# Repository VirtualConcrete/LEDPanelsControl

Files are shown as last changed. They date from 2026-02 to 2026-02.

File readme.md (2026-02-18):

# DMX HUB12 LED driver

Use any HUB12 display with DMX control.

### Schematics

The board is a simple Arduino Nano --> HUB12 adapter with DMX input using the SN75176 differential bus transciver.
XLR 3 pin is used for DMX input.
The power supply is +5V via screw terminals.

### Dependencies

- [DMD2](https://github.com/freetronics/DMD2)
- [DMXSerial](https://github.com/mathertel/DmxSerial)

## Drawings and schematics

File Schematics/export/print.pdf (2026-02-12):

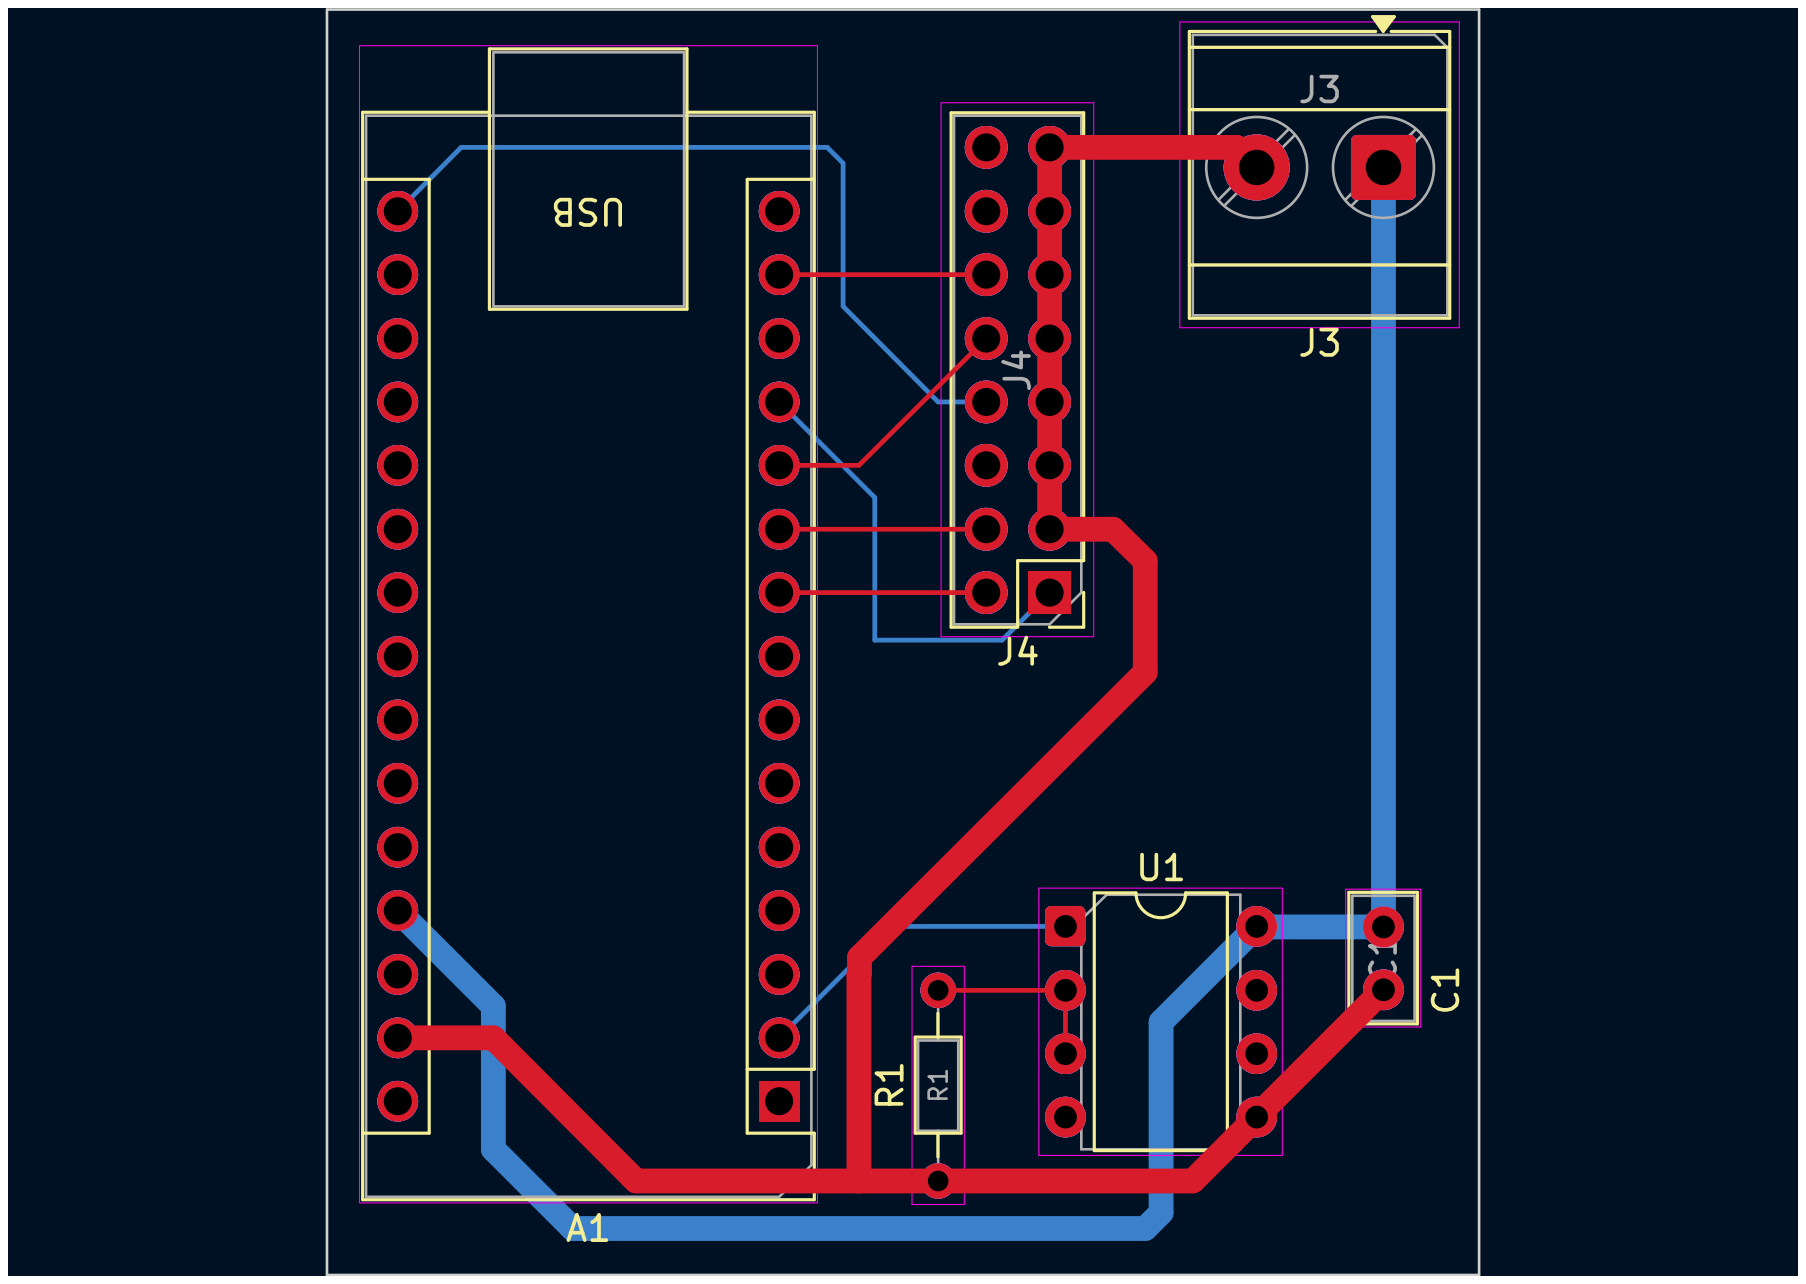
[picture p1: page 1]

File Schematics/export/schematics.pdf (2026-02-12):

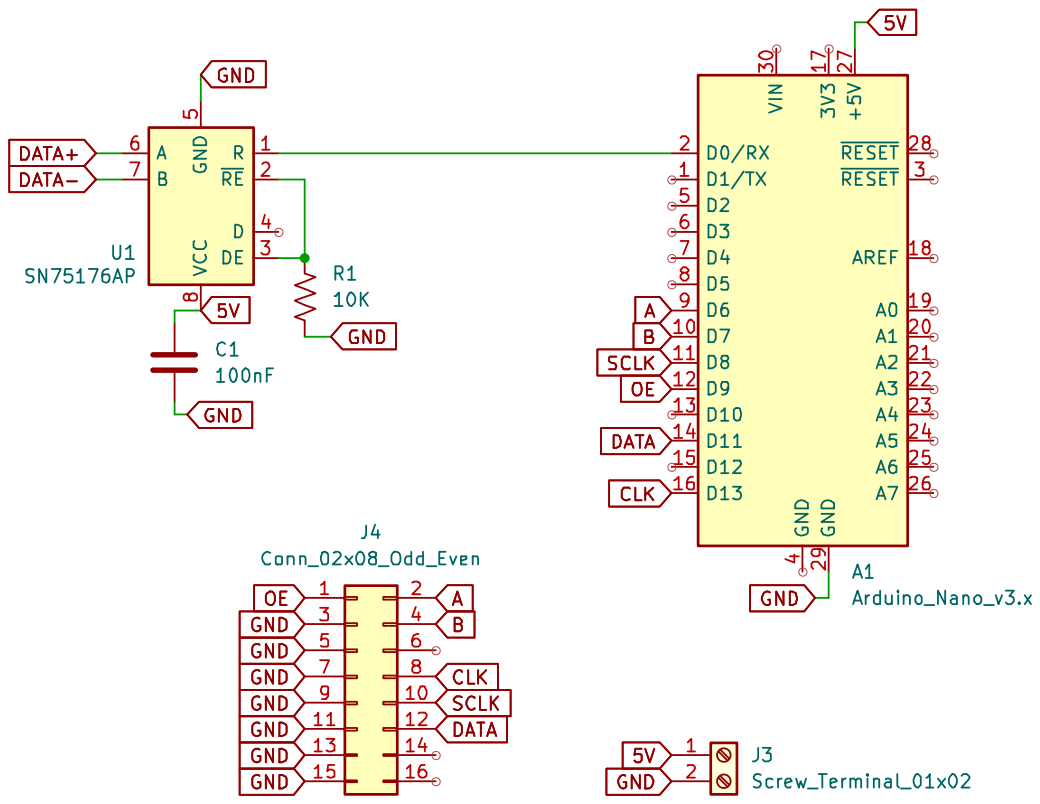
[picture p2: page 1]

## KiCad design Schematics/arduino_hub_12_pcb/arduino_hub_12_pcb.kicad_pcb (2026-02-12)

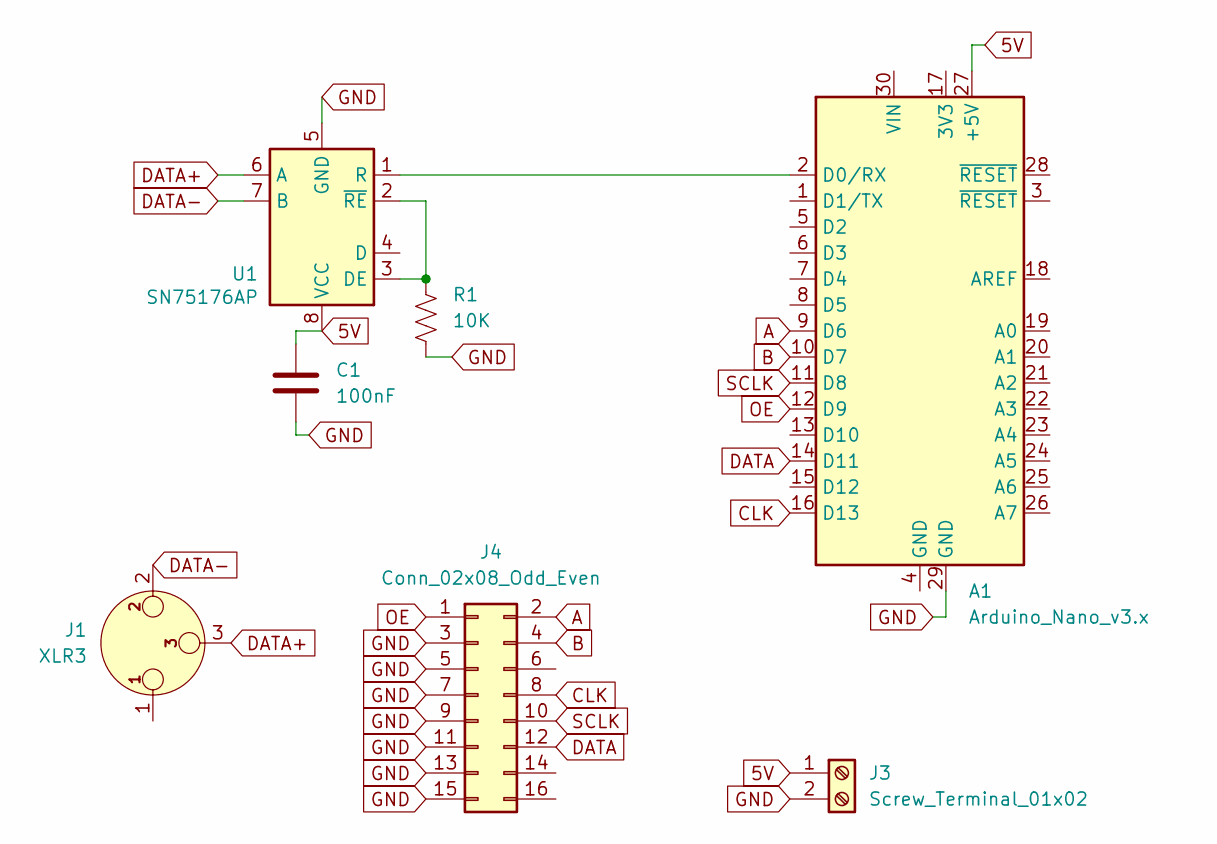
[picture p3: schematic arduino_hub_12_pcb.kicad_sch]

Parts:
A1: Arduino_Nano_v3.x; Arduino_Nano
C1: 100nF; C_Disc_D5.0mm_W2.5mm_P2.50mm
J1: XLR3; Jack_XLR_Neutrik_NC3FAH-0_Horizontal
J3: Screw_Terminal_01x02; TerminalBlock_Phoenix_MKDS-3-2-5.08_1x02_P5.08mm_Horizontal
J4: Conn_02x08_Odd_Even; PinHeader_2x08_P2.54mm_Vertical
R1: 10K; R_Axial_DIN0204_L3.6mm_D1.6mm_P7.62mm_Horizontal
U1: SN75176AP; DIP-8_W7.62mm

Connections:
5V: A1.27 (+5V), C1.1, J3.1, U1.8 (VCC)
A: A1.9 (D6), J4.2
B: A1.10 (D7), J4.4
CLK: A1.16 (D13), J4.8
DATA: A1.14 (D11), J4.12
DATA+: J1.3, U1.6 (A)
DATA-: J1.2, U1.7 (B)
GND: A1.29 (GND), C1.2, J3.2, J4.3, J4.5, J4.7, J4.9, J4.11, J4.13, J4.15, R1.1, U1.5 (GND)
unnamed: A1.2 (D0/RX), U1.1 (R)
unnamed: R1.2, U1.2 (~RE), U1.3 (DE)
OE: A1.12 (D9), J4.1
SCLK: A1.11 (D8), J4.10

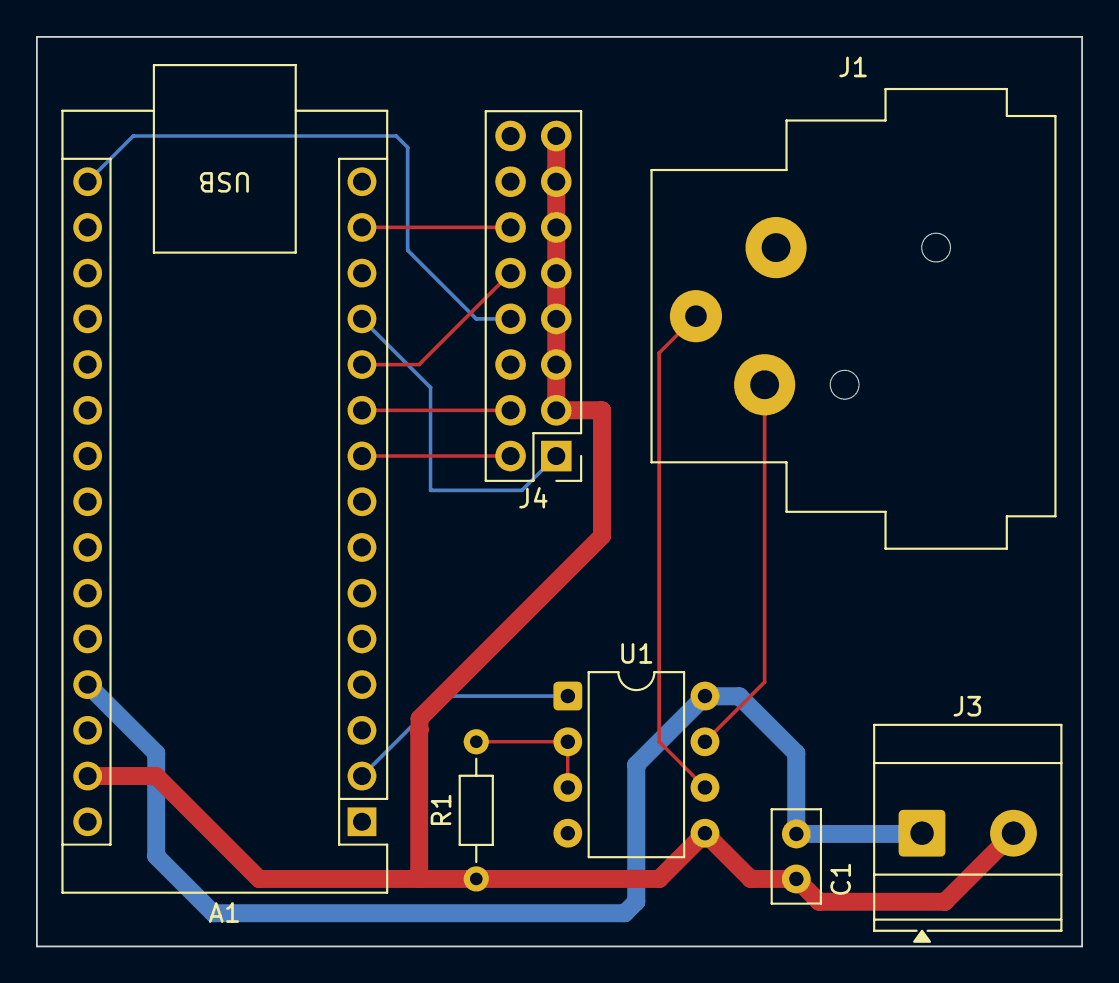
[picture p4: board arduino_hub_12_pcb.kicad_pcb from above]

Board: 2 copper layers, 58.1 x 50.5 mm, 7 parts (0 on the bottom side), 12 nets.

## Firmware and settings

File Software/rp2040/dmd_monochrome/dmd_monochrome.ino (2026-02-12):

/*--------------------------------------------------------------------------------------
 Demo code for Monochrome DMD panels

 DMD_STM32a example code for STM32F4 & RP2040 boards
 ------------------------------------------------------------------------------------- */
// choose between Parallel ans SPI wiring
// comment line below for SPI connection
#define DMD_PARA
/*--------------------------------------------------------------------------------------
  Includes
--------------------------------------------------------------------------------------*/
#if defined(DMD_PARA)
#include "DMD_Monochrome_Parallel.h"
#else
#include "DMD_MonoChrome_SPI.h"
#endif

//Number of panels in x and y axis
#define DISPLAYS_ACROSS 2
#define DISPLAYS_DOWN 1

// Enable of output buffering
// if true, changes only outputs to matrix after
// swapBuffers(true) command
// If dual buffer not enabled, all output draw at matrix directly
// and swapBuffers(true) command do nothing
#define ENABLE_DUAL_BUFFER true

// ----- Select pins for P10 matrix connection ------------
/* =================== *
*     STM32F4 pins     *
*  =================== */
// pins A, B, SCLK may be any digital I/O, pin nOE should be Timer3 PWM pin as PB0,PB1
// if connect as SPI, do not use corresponding MiSO pin - PA6 for SPI1 and PB14 for SPI2

#if (defined(__STM32F1__) || defined(__STM32F4__))
#define DMD_PIN_A PA1
#define DMD_PIN_B PA3
#define DMD_PIN_nOE PB1
#define DMD_PIN_SCLK PA15
//#define DMD_PIN_SCLK PA0


#if defined(DMD_PARA)
//=== Config for STM32 Parallel connect ====
// pins for rows at x axis
// example for two rows
// all those pins must be selected from same port!
#ifdef USE_UPPER_8BIT
uint8_t pins[] = { PB9, PB11, PB13 };  // CLK , row1, row 2
#else
uint8_t pins[] = { PA5, PA7, PA6 };  // CLK , row1, row 2
#endif

#else
//=== Config for STM32 SPI connect ====
// SPI specific pins as CLK and R_DATA has predefined values:
//   for SPI(1) CLK = PA5  R_DATA = PA7
//   for SPI(2) CLK = PB13  R_DATA = PB15
// --------------------------------------------------------
#endif
#endif
/* =================== *
*     RP2040 pins     *
*  =================== */
#if defined(ARDUINO_ARCH_RP2040)
#if defined(DMD_PARA)
#define DMD_PIN_A 1
#define DMD_PIN_B 2
#define DMD_PIN_nOE 14
#define DMD_PIN_SCLK 15

// These pins must be consecutive in ascending order
uint8_t pins[] = { 6, 7, 8 };  // CLK , row1, row 2
#else
#error Monochrome_SPI mode unsupported for Rasberry Pico RP2040
#endif
#endif

#if defined(DMD_PARA)
//Fire up the DMD object as dmd
DMD_Monochrome_Parallel dmd(DMD_PIN_A, DMD_PIN_B, DMD_PIN_nOE, DMD_PIN_SCLK, pins, DISPLAYS_ACROSS, DISPLAYS_DOWN,ENABLE_DUAL_BUFFER);
#else

//=== Config for SPI connect ====
SPIClass dmd_spi(1);
DMD_MonoChrome_SPI dmd(DMD_PIN_A, DMD_PIN_B, DMD_PIN_nOE, DMD_PIN_SCLK, DISPLAYS_ACROSS, DISPLAYS_DOWN, dmd_spi, ENABLE_DUAL_BUFFER);
#endif


// Fonts includes
#include "st_fonts/UkrRusArial14.h"
#pragma GCC diagnostic ignored "-Wnarrowing"
#pragma GCC diagnostic ignored "-Woverflow"
#include "gfx_fonts/GlametrixLight12pt7b.h"
#include "gfx_fonts/GlametrixBold12pt7b.h"
#pragma GCC diagnostic warning "-Wnarrowing"
#pragma GCC diagnostic warning "-Woverflow" 
// --- Define fonts ----
// DMD.h old style font
DMD_Standard_Font UkrRusArial_F(UkrRusArial_14);

// GFX font with sepatate parts for Latin and Cyrillic chars
DMD_GFX_Font GlametrixL((uint8_t*)&GlametrixLight12pt7b,(uint8_t*)&GlametrixLight12pt8b_rus,0x80,13);


/*--------------------------------------------------------------------------------------
  UTF8 char recoding
 
--------------------------------------------------------------------------------------*/
int utf8_rus(char* dest, const unsigned char* src) {
  
  uint16_t i, j;
  for ( i =0, j =0; src[i]; i++) {
   if ((src[i] == 0xD0 )&& src[i+1])  { dest[j++] = src[++i] - 0x10;}
    else if ((src[i] == 0xD1 )&& src[i+1]) {dest[j++] = src[++i] + 0x30;  }
    else dest[j++] = src[i];
  }
  dest[j] ='\0';
  return j;
}

/*--------------------------------------------------------------------------------------
  setup
  Called by the Arduino architecture before the main loop begins
--------------------------------------------------------------------------------------*/

void setup(void)
{
   
   // initialize DMD objects
   // scan DMD row each 700 us
    dmd.init(700);
    dmd.setBrightness(80);
   
}

/*--------------------------------------------------------------------------------------
  loop
  Arduino architecture main loop
--------------------------------------------------------------------------------------*/
void loop(void)
{

    // text
    const char m[] = "Привет Ардуино!";
    // transcode message to UTF for use with GFX fonts
    char k[30];
    utf8_rus(k, (const unsigned char* )m);

    // but initially select standard font
    dmd.selectFont(&UkrRusArial_F);

    // shift steps in pixels for running text (positive - shift right, negative - left)
    int8_t step[] = { 1,-1,-2,2 };
    // running text shift interval
    uint32_t interval = 50;
    
    uint32_t prev_step = millis();
    uint8_t i = 0, b = 0;
    uint8_t test = 255;
    uint8_t test_cnt = 4;

     // Cycle for tests:
    // -- running texts moving at x and y axis with single and double speed
    // -- brightness control
    // -- vertical scrolling message
    while (1) {
        if ((millis() - prev_step) > interval) {
            prev_step = millis();  // moved to the start of the loop to prevent "scroll not smooth" issue
            if (test >= test_cnt) {
                test = 0;
                // draw message
                dmd.drawMarqueeX(m, -1 * (dmd.stringWidth(m)), 0);
                dmd.swapBuffers(true);

            }
            switch (test) {
              // moving text at x axis
            case 0:
                if (dmd.stepMarquee(step[i], 0) & MARQUEE_OUT_OF_SCREEN) { // if text is reached screen bounds

                    dmd.clearScreen(true);
                    i++;
                    // if all moving finished
                    if (i > 3) {
                      // go to next stage
                        i =0;
                        test++;
                        dmd.drawMarqueeX(m, 0, 0);
                    }
                    else {
                        if (step[i] < 0) dmd.drawMarqueeX(m, dmd.width() - 1, 0);
                        else dmd.drawMarqueeX(m, -1 * dmd.stringWidth(m), 0);
                    }
                }
              
                // output mem buffer to matrix
                dmd.swapBuffers(true);
                break;
            
            
            // change brightness
            case 1:
                b++;
                dmd.setBrightness(b);
                if (b > 200) {
                    test++;
                    b = 80;
                    i = 0;
                    dmd.setBrightness(b);
                    dmd.drawMarqueeX(m, 0, 0);
                }
                dmd.swapBuffers(true);
                break;

            // moving text at y axis
            case 2:
                if (dmd.stepMarquee(0, step[i]) & MARQUEE_OUT_OF_SCREEN) {

                    // clear the screen
                    dmd.clearScreen(true);
                    // select new moving speed
                    i++;
                    // if all moving finished
                    if (i > 3) {
                      // go to next stage
                        test++;
                        // select GFX font for vertical scroll
                        dmd.selectFont(&GlametrixL);
                        dmd.drawMarquee(k, strlen(k), dmd.width() - 1, 0, 1);

                    }
                    else {
                        if (step[i] < 0) dmd.drawMarqueeX(m, 0, dmd.height());
                        else dmd.drawMarqueeX(m, 0, 0);
                    }
                }
                // output mem buffer to matrix
                dmd.swapBuffers(true);
                break;

            // vertical scrolling    
            case 3:

                dmd.stepMarquee(-1, 0, 1);
                dmd.swapBuffers(true);
                break;

            }

           
        }
    }
}

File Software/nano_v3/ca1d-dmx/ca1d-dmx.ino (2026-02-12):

#include <DMD2.h>
#include <SPI.h>

#include <DMXSerial.h>


#define DISPLAYS_WIDE 2
#define DISPLAYS_HIGH 1

SoftDMD dmd(DISPLAYS_WIDE, DISPLAYS_HIGH);
DMDFrame frame(64, 16);


#define ROW_LENGTH 64

enum RenderState {
  Play,
  Pause,
  Stop,
};

RenderState renderState;

uint8_t CURRENT_RULE = 30;
uint8_t DATA[ROW_LENGTH * 2];

uint8_t* current_cell_states;
uint8_t* next_cell_states;
uint8_t* temp;

int startChannel = 1;

int speed = 255;


int stateBasedOnNeighbors(int rule, int left, int center, int right) {
  return(rule >> (left << 2 | center << 1 | right)) & 1;
}

void setStartingValues(bool rand_start) {
  renderState = Pause;
  if(rand_start) {
    for(int i = 0; i < ROW_LENGTH; i++)
      current_cell_states[i] = rand() % 2;
  } else {
    for(int i = 0; i < ROW_LENGTH; i++)
      current_cell_states[i] = 0;
    current_cell_states[ROW_LENGTH / 2] = 1;
  }
}

void setup() {
  DMXSerial.init(DMXReceiver);

  dmd.setBrightness(255);
  dmd.begin();

  current_cell_states = DATA;
  next_cell_states = DATA + ROW_LENGTH;

  current_cell_states[ROW_LENGTH / 2] = 1;

  DMXSerial.write(startChannel, 45);
  DMXSerial.write(startChannel + 1, 0);
  DMXSerial.write(startChannel + 2, 0);

  renderState = Play;
}

uint8_t row_to_update = 0;

uint8_t restart_timer = 0;

void loop() {
  speed = 1320 - (DMXSerial.read(startChannel) + 5) * 5;
  uint8_t ch2_read = DMXSerial.read(startChannel + 1);
  if(ch2_read < 64)
    CURRENT_RULE = 30;
  else if(ch2_read >= 64 && ch2_read < 128)
    CURRENT_RULE = 57;
  else if(ch2_read >= 128 && ch2_read < 192)
    CURRENT_RULE = 73;
  else
    CURRENT_RULE = 90;
  
  uint8_t ch3_read = DMXSerial.read(startChannel + 2);

  if((ch3_read > 225) && (ch3_read <= 240))
    setStartingValues(true);
  else if(ch3_read > 240)
    setStartingValues(false);

  if(renderState == Pause) {
    if(ch3_read == 0)
      renderState = Play;
  }

  if(renderState == Play) {
    if(row_to_update == 15)
      frame.scrollY(-1);

    for(int i = 0; i < ROW_LENGTH; i++)
      frame.setPixel(i, row_to_update, (current_cell_states[i]? GRAPHICS_ON : GRAPHICS_OFF));
    
    for(int i = 0; i < ROW_LENGTH; i++) {
      int left = current_cell_states[((i - 1) + ROW_LENGTH) % ROW_LENGTH];
      int curr = current_cell_states[i];
      int right = current_cell_states[(i + 1) % ROW_LENGTH];
      
      next_cell_states[i] = stateBasedOnNeighbors(CURRENT_RULE, left, curr, right);
    }

    dmd.copyFrame(frame, 0, 0);

    temp = current_cell_states;
    current_cell_states = next_cell_states;
    next_cell_states = temp;

    if(row_to_update < 15)
      row_to_update++;

    delay(speed);
  }
}
